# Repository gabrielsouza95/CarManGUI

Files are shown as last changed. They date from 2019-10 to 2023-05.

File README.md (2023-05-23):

# CarManGUI

### The Project
 
The project is being developed in partnership with FEB Racing([facebook](https://www.facebook.com/equipefebracing))([instagram](https://www.instagram.com/febracing/?hl=pt)), the formula SAE team from Unesp, for the construction of a device for the team's car.

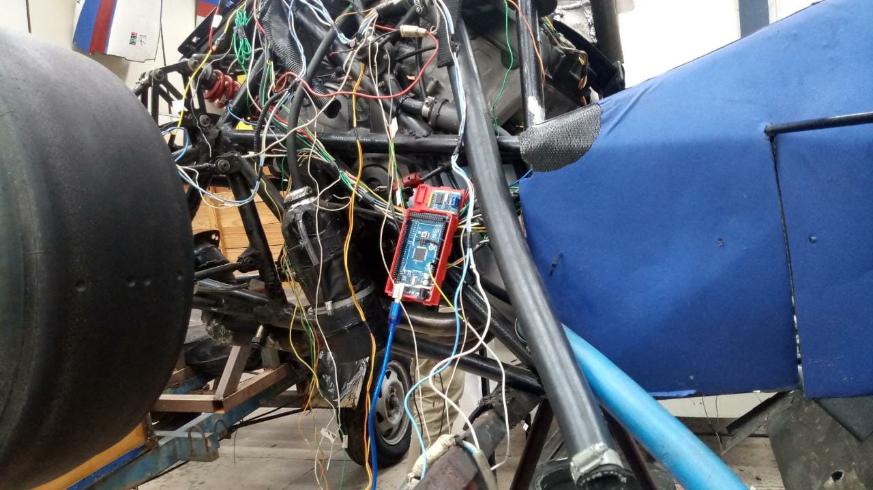
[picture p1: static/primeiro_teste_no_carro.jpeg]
First test on the car


In summary, it consists of:

1. Sensors placed on the car.
2. Recording of data collected from the sensors into a file for later analysis.
3. Displaying the data to the driver through a user interface and, in the future, to the team in the pit with the possibility of simple communication between the team and the driver:
   
    i. For example, showing the driver that a flag of color x has been given.
4. A plotter for data visualization and analysis.

### The Hardware
   
The current hardware of the project consists of:

1. 1 [Arduino Mega](https://www.arduino.cc/en/Guide/ArduinoMega2560)
2. Several sensors, including:

   i. 3 [MPU6050](https://www.letscontrolit.com/wiki/index.php/MPU6050) accelerometers and gyroscopes

   ii. 4 [MLX90614](https://forum.arduino.cc/index.php?topic=577921.0) infrared temperature sensors

   iii. 4 [KY003](https://www.instructables.com/Arduino-Magnetic-FIELD-Detector-Using-the-KY-003-o/) hall effect sensors

   iv. 4 potentiometers for suspension travel verification
   
    v. 1 brake line pressure sensor

3. 1 [0.96" OLED display](https://randomnerdtutorials.com/guide-for-oled-display-with-arduino/) that communicates via I2C
4. 3 buttons connected with a common pull-up
5. 1 [Raspberry Pi](https://circuitdigest.com/simple-raspberry-pi-projects-for-beginners)
6. 1 [3.5" touch displa](https://www.youtube.com/watch?v=Fj3wq98pd20), mounted on top of the Raspberry Pi, enabled via Raspbian
7. 1 4052 multiplexer
8. 1 [MCP2515](https://www.electronicshub.org/arduino-mcp2515-can-bus-tutorial/) adapter

In addition, the following are being implemented:
  - 4 [ATtiny85](https://thewanderingengineer.com/2014/02/17/attiny-i2c-slave/) microcontrollers.

### The Software

For the project implementation, C# is being used for the user interface, using a .NET Framework 4 project and [Mono].(https://www.mono-project.com/docs/getting-started/install/linux/#debian-ubuntu-and-derivatives)In the future, the Python will be used, which is compatible with Raspbian.

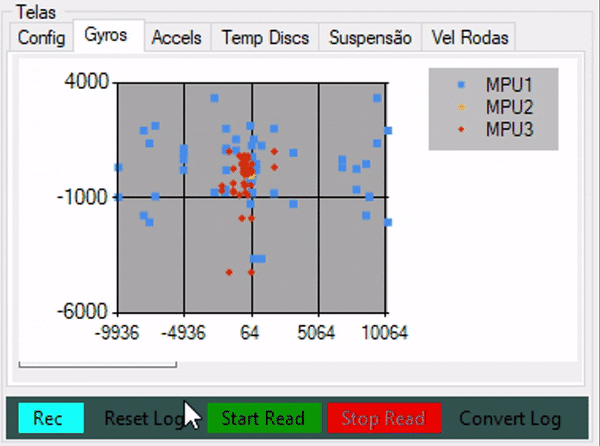
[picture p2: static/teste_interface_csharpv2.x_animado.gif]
teste_interface_csharpv2.x_animado


__The GIF shows a test of the C# window, with a 2D graph implemented, printing the values of 2 out of 3 accelerometer axes as data points while I sway the sensor.__

The project also utilizes Python, R, and C++ (Arduino, Processing, and an attempt to script for serial communication).

### Current Status

_-_ The project currently has a C# window developed to interface with the user through the Raspberry Pi's 3.5" display. It handles the initialization and termination of communication with the Arduino, controls when data recording starts, provides feedback when recording is in progress, and allows the recording to be stopped at any time*. It also displays sensor data on separate screens for better visualization.

_-_ The C# window did not function correctly on the Raspberry Pi after changing from manually using a thread to utilizing serial port events in C#. From my findings, the compatibility software Mono that I am using on the Raspberry Pi does not have the serial port event compatibility implemented.

_-_ Since the C# window did not work correctly on the Raspberry Pi, a 0.96" OLED display is being used to show desired information to the driver. It includes 2 buttons for menu selection, one for moving forward in the options and another for going back. The third button controls when the Arduino should start or stop recording. A SD card shield was supposed to be used, but it also did not work.

_-_ A Python window was developed to enable taking the functioning equipment to the competition since the SD module did not work directly connected to the Arduino. With this window, the Arduino can establish a connection and generate the log file. Due to the pandemic, it has not been possible to test the equipment on the team's car, but I will test it on my Corsa and post the results here. I will also test before and after installing the sway bar, as at that time, entry-level cars came so barebones that they didn't even come with safety features like the sway bar or the engine protection shield to reduce costs.

_-_ A test bench was created to facilitate the current bench tests, as seen in the following two images:

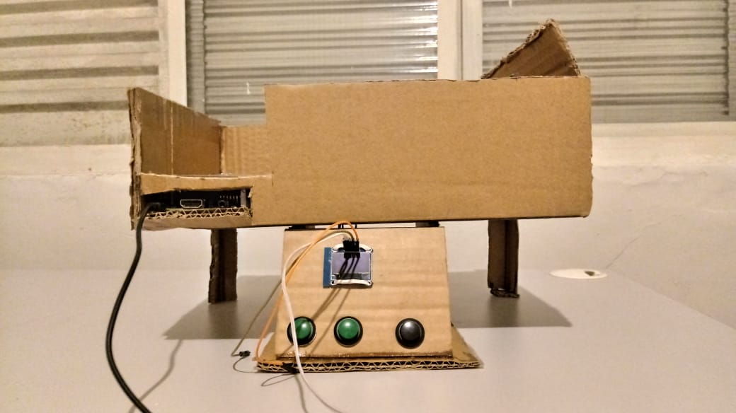
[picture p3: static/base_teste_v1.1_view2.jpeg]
Front view of the test bench


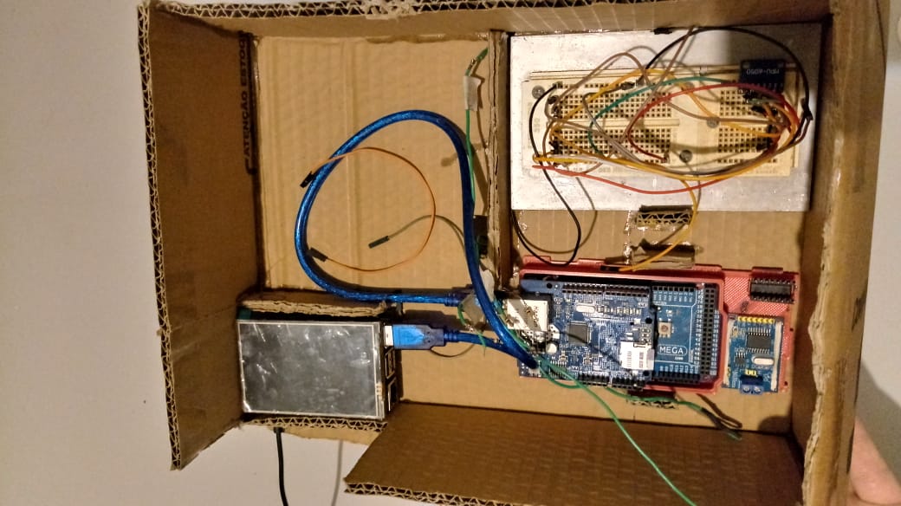
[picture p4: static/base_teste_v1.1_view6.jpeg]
Top view of the test bench


_-_ A flag alert feature was implemented to inform the driver of any conditions that require attention. This implementation allows for other necessary alerts to be conveyed to the driver. The image below shows how the accelerometer information was displayed:

Flag alert test

_-_ The interface for accelerometer data has been improved to be more comprehensible for the driver. The lateral and forward-backward acceleration axes were chosen for implementation in how the point should move. I took inspiration from the G-force display in Gran Turismo. The following image shows the first version:

First version of the accelerometer UI

_-_ In the next image, the second version of the interface can be seen:

Second version of the accelerometer UI

### Planned Implementations

_-_ I plan to use Johnny-Five with Node.js to communicate between the Raspberry Pi and Arduino. I am also studying the possibility of creating an interface with React and preparing it for accessing the car via the internet on a computer in the pit using a React web page or even a mobile app with React Native.

_-_ As mentioned in the software section, before implementing with JS([JonhyFive](http://johnny-five.io/),[Node](https://www.instructables.com/NodeJs-and-Arduino/),[React](https://awot.net/en/guide/tutorial.html),ReactNative), I will likely implement a version using Python, which guarantees compatibility with Raspbian.

_-_ The ATtiny85 microcontrollers will be used as speed sensors, placed between the Arduino and the hall effect sensor, to correctly count pulses per time interval. If we were to directly use the 4 hall effect sensors on the Arduino, [the response would be poor](https://forum.arduino.cc/index.php?topic=519300.0) due to how wheel speed is calculated by sampling pulses per time. This is because it utilizes interrupt routines of the processor for such tasks. The idea is to have the ATtiny85 connected as a [slave on the I2C bus](https://thewanderingengineer.com/2014/02/17/attiny-i2c-slave/), and when the Arduino requests it, the ATtiny85 will send the current wheel speed, performing the interrupt calculations directly on the ATtiny85, which supports this. 

_-_ I am considering migrating the project directly to an [ESP8266](https://github.com/esp8266/Arduino) to not only utilize WiFi functionality in conjunction with the Raspberry Pi but also to improve the speed of the hardware responsible for capturing sensor data. This would allow for better sampling of sensor data and the possibility of adding more data capture, such as a CAN adapter and additional sensors.

_-_ I want to include reading the CAN bus in the equipment. I am currently trying to make it work with the [MCP2515](https://www.electronicshub.org/arduino-mcp2515-can-bus-tutorial/) adapter, but so far, I have been unable to initialize the adapter to proceed with reading the data from the engine control unit (ECU) to associate it with the sensor data log added by the project.

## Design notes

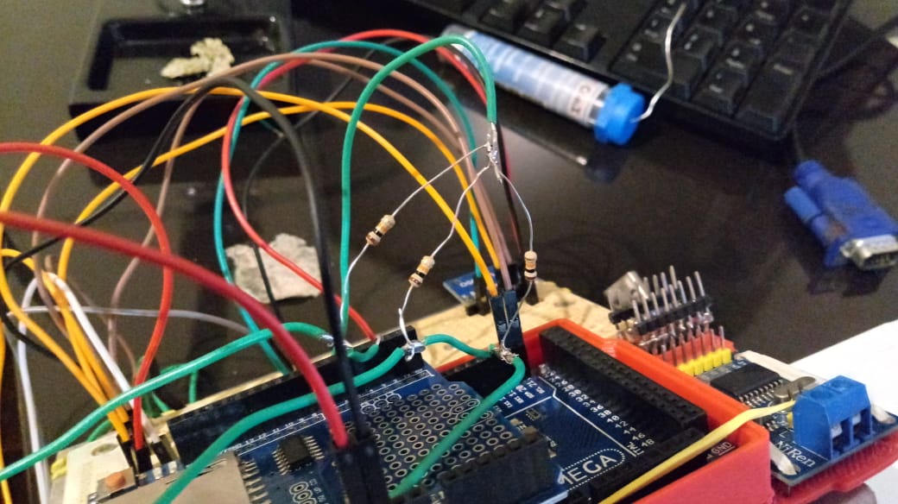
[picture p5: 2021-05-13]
static/pull_up_botões.jpeg

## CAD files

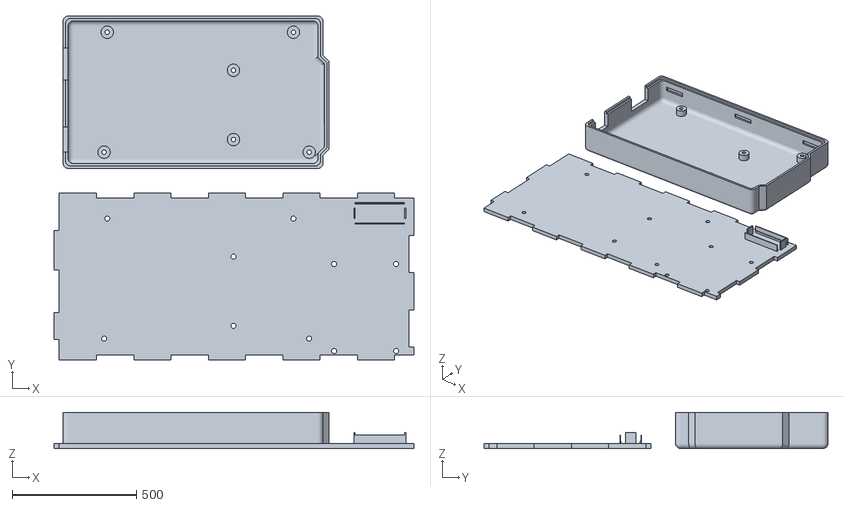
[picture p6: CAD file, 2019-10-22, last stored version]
3DArduinoCase/files/arduino_mega_bottom_extra v9.stl
1446.8 x 1384.3 x 145.3

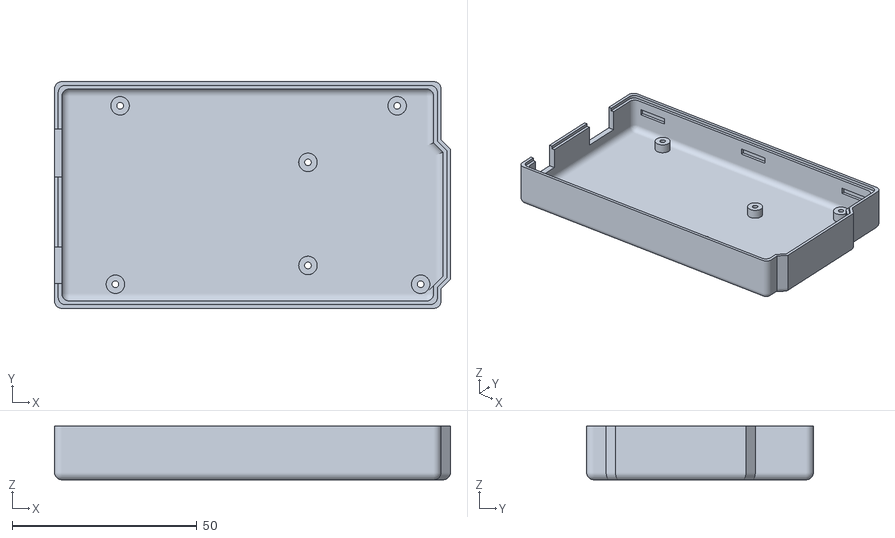
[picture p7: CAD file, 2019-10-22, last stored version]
3DArduinoCase/files/arduino_mega_bottom.stl
107.1 x 61.3 x 14.5

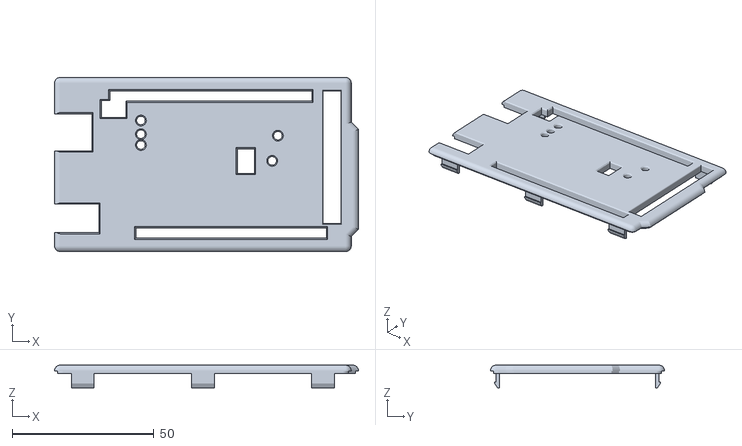
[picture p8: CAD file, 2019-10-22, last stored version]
3DArduinoCase/files/arduino_mega_top.stl
107.1 x 61.3 x 8.00

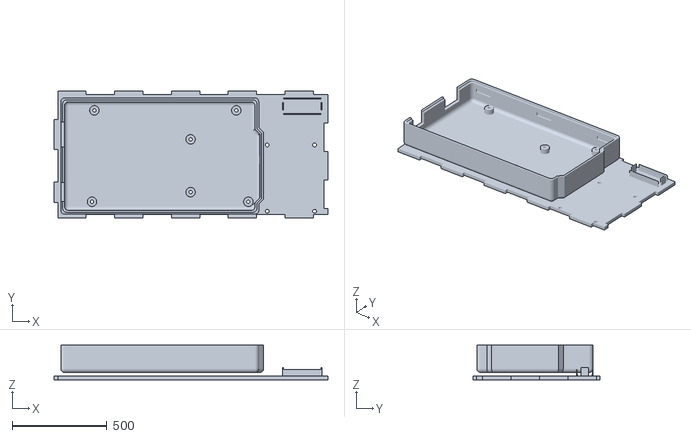
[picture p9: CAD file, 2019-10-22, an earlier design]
3DArduinoCase/files/arduino_mega_bottom_extra v8.stl
1446.8 x 671.8 x 184.3

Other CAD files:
3DArduinoCase/files/arduino_mega_bottom_extra ajutado.stl

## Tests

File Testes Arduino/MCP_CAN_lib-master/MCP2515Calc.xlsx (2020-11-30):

MCP2515 Configuration Register Calculator
Crystal Frequency | 16 | MHz | Baud Register Values |  |  |  | Misc Register Values
Baud Rate | 250 | kbs | Baud Rate Prescaler (BRP) |  |  | 1 | PS2 Bit Time Mode (BTLMODE) |  |  | 1
 |  |  | Propogation Segment |  |  | 1 | Sample Mode (SAM) |  |  | 1
Time Quantum | 0.25 | microseconds | Phase Segment 1 (PS1) |  |  | 6 | Start-of Frame Signal (SOF) |  |  | 1
Bit Time | 4 | microseconds | Phase Segment 2 (PS2) |  |  | 5 | Wake-Up Filter (WAKFIL) |  |  | 0
Time Quantum Max | 16 |  | Synchronization Jump Width (SJW) |  |  | 1
Prescaler Setting | 1 |  | Adjust BRP To Get A Nice Whole Time Quantum Max Value
SJW | 2 | x TQ | PropSeg + PS1 >= PS2 |  |  | Bit Sample Point Occurs Between PS1 and PS2
SyncSeg | 1 | x TQ | PropSeg + PS1 >= TDELAY |  |  | Typically, the TDELAY is 1-2 TQ
PropSeg | 2 | x TQ | PS2 > SJW
PS1 | 7 | x TQ | MCP2515 Baud Registers
PS2 | 6 | x TQ | msb |  |  |  |  |  |  | lsb
 | 16 | Total TQ | 7 | 6 | 5 | 4 | 3 | 2 | 1 | 0
Register CNF1 | 41 | 01000001 | 0 | 1 | 0 | 0 | 0 | 0 | 0 | 1
 |  |  | SJW |  | BRP
Register CNF2 | F1 | 11110001 | 1 | 1 | 1 | 1 | 0 | 0 | 0 | 1
 |  |  | BTLMODE | SAM | PS1 |  |  | Prop
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

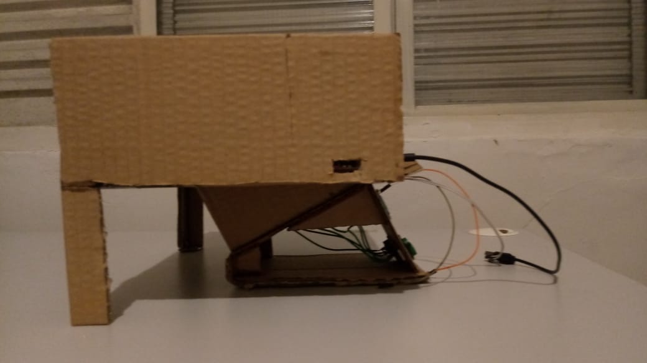
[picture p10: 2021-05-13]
static/base_teste_v1.1_view3.jpeg

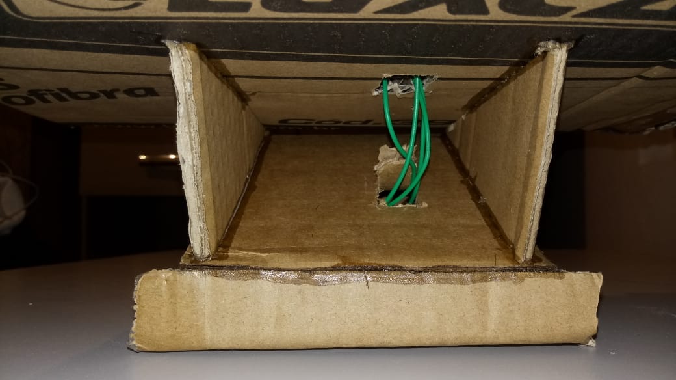
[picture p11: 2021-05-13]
static/base_teste_v1.1_view5.jpeg

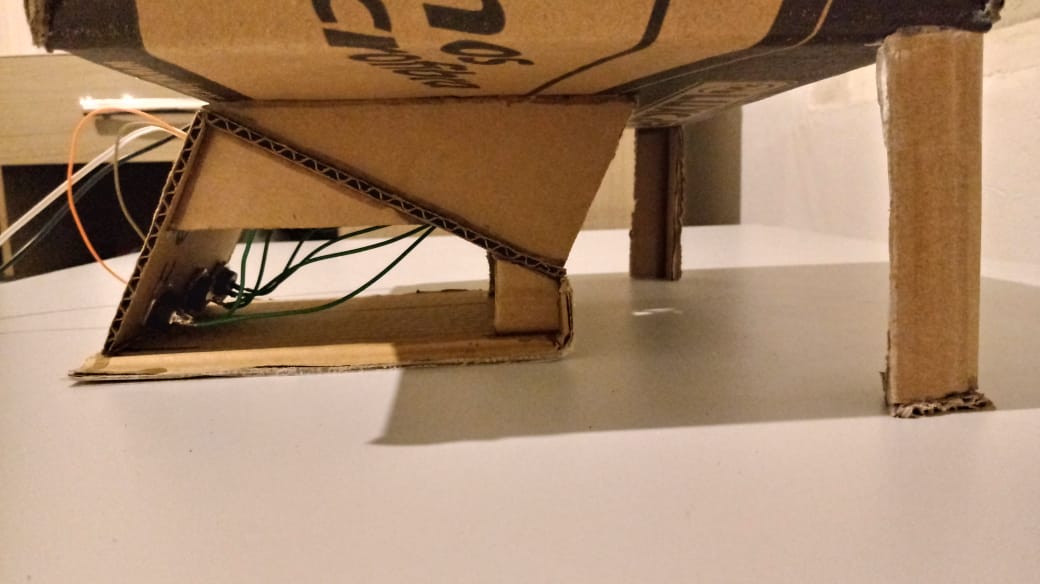
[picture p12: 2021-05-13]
static/base_teste_v1.1_view4.jpeg

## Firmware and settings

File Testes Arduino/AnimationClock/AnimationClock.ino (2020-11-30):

#include <SPI.h>
#include <Wire.h>
#include <Adafruit_GFX.h>
#include <Adafruit_SSD1306.h> 
//#include <Fonts/FreeSans9pt7b.h>
//#include <Fonts/FreeSans12pt7b.h>
//#include <Fonts/FreeSans18pt7b.h>

#define ARRAY_WIDTH 288
#define ARRAY_ELEMS 28
#define OLED_RESET -1
Adafruit_SSD1306 display(OLED_RESET);
const unsigned char PROGMEM frames  [28] [288] = { {0x00, 0x00, 0x00, 0x00, 0x00, 0x00, 0x00, 0x78, 0x00, 0x00, 0x3C, 0x00, 0x01, 0xFF, 0x00, 0x00, 0xFF, 0x80, 0x07, 0xEF, 0x00, 0x00, 0xFB, 0xE0, 0x0F, 0x0E, 0x00, 0x00, 0x70, 0xF0, 0x1E, 0x3C, 0x1F, 0xF0, 0x3C, 0x30, 0x18, 0x38, 0x7F, 0xFF, 0x1C, 0x38, 0x18, 0xF3, 0xF8, 0x2F, 0xCF, 0x1C, 0x38, 0xE7, 0xC0, 0x03, 0xE7, 0x1C, 0x33, 0xDE, 0x00, 0x00, 0x7B, 0xCC, 0x33, 0xBC, 0x00, 0x00, 0x3D, 0xCC, 0x3F, 0x78, 0x00, 0x00, 0x1E, 0xFC, 0x3F, 0x70, 0x00, 0x00, 0x0E, 0x7C, 0x3C, 0xE0, 0x00, 0x00, 0x07, 0x3C, 0x39, 0xC0, 0x00, 0x00, 0x03, 0x9C, 0x11, 0x82, 0x00, 0x00, 0x01, 0x88, 0x03, 0x87, 0x00, 0x00, 0x01, 0xC0, 0x03, 0x03, 0x80, 0x00, 0x00, 0xC0, 0x07, 0x01, 0xC0, 0x00, 0x00, 0xE0, 0x06, 0x00, 0xE0, 0x00, 0x00, 0x60, 0x0E, 0x00, 0x70, 0x00, 0x00, 0x60, 0x0E, 0x00, 0x38, 0x00, 0x00, 0x70, 0x0C, 0x00, 0x1C, 0x00, 0x00, 0x30, 0x0C, 0x00, 0x0E, 0x00, 0x00, 0x30, 0x0C, 0x00, 0x7F, 0x80, 0x00, 0x30, 0x0C, 0x01, 0xFF, 0x80, 0x00, 0x30, 0x0C, 0x00, 0x55, 0x00, 0x00, 0x30, 0x0C, 0x00, 0x00, 0x00, 0x00, 0x30, 0x0C, 0x00, 0x00, 0x00, 0x00, 0x30, 0x0C, 0x00, 0x00, 0x00, 0x00, 0x30, 0x0E, 0x00, 0x00, 0x00, 0x00, 0x70, 0x06, 0x00, 0x00, 0x00, 0x00, 0x60, 0x06, 0x00, 0x00, 0x00, 0x00, 0x60, 0x07, 0x00, 0x00, 0x00, 0x00, 0xE0, 0x03, 0x00, 0x00, 0x00, 0x00, 0xC0, 0x03, 0x80, 0x00, 0x00, 0x01, 0xC0, 0x01, 0xC0, 0x00, 0x00, 0x03, 0x80, 0x01, 0xC0, 0x00, 0x00, 0x03, 0x80, 0x00, 0xE0, 0x00, 0x00, 0x07, 0x00, 0x00, 0x70, 0x00, 0x00, 0x0E, 0x00, 0x00, 0x78, 0x00, 0x00, 0x1E, 0x00, 0x00, 0xFE, 0x00, 0x00, 0x7F, 0x00, 0x01, 0xCF, 0x80, 0x01, 0xF3, 0x80, 0x03, 0x83, 0xF0, 0x1F, 0xC1, 0xC0, 0x07, 0x00, 0xFF, 0xFF, 0x00, 0xE0, 0x06, 0x00, 0x1F, 0xF8, 0x00, 0x60, 0x00, 0x00, 0x00, 0x00, 0x00, 0x00, 0x00, 0x00, 0x00, 0x00, 0x00, 0x00}//;
/*const unsigned char PROGMEM frame1  [] =*/	 , {0x00, 0x00, 0x00, 0x00, 0x00, 0x00, 0x00, 0x78, 0x00, 0x00, 0x3C, 0x00, 0x01, 0xFF, 0x00, 0x00, 0xFF, 0x80, 0x07, 0xEF, 0x00, 0x00, 0xFB, 0xE0, 0x0F, 0x0E, 0x00, 0x00, 0x70, 0xF0, 0x1E, 0x3C, 0x1F, 0xF0, 0x3C, 0x30, 0x18, 0x38, 0x7F, 0xFF, 0x1C, 0x38, 0x18, 0xF3, 0xF8, 0x2F, 0xCF, 0x1C, 0x38, 0xE7, 0xC0, 0x03, 0xE7, 0x1C, 0x33, 0xDE, 0x00, 0x00, 0x7B, 0xCC, 0x33, 0xBC, 0x00, 0x00, 0x3D, 0xCC, 0x3F, 0x78, 0x00, 0x00, 0x1E, 0xFC, 0x3F, 0x70, 0x00, 0x00, 0x0E, 0x7C, 0x3C, 0xE0, 0x00, 0x00, 0x07, 0x3C, 0x39, 0xC0, 0x00, 0x00, 0x03, 0x9C, 0x11, 0x83, 0x80, 0x00, 0x01, 0x88, 0x03, 0x81, 0xC0, 0x00, 0x01, 0xC0, 0x03, 0x00, 0xE0, 0x00, 0x00, 0xC0, 0x07, 0x00, 0xE0, 0x00, 0x00, 0xE0, 0x06, 0x00, 0x70, 0x00, 0x00, 0x60, 0x0E, 0x00, 0x38, 0x00, 0x00, 0x60, 0x0E, 0x00, 0x1C, 0x00, 0x00, 0x70, 0x0C, 0x00, 0x0E, 0x00, 0x00, 0x30, 0x0C, 0x00, 0x07, 0x00, 0x00, 0x30, 0x0C, 0x00, 0x7F, 0x80, 0x00, 0x30, 0x0C, 0x01, 0xFF, 0x80, 0x00, 0x30, 0x0C, 0x00, 0x55, 0x00, 0x00, 0x30, 0x0C, 0x00, 0x00, 0x00, 0x00, 0x30, 0x0C, 0x00, 0x00, 0x00, 0x00, 0x30, 0x0C, 0x00, 0x00, 0x00, 0x00, 0x30, 0x0E, 0x00, 0x00, 0x00, 0x00, 0x70, 0x06, 0x00, 0x00, 0x00, 0x00, 0x60, 0x06, 0x00, 0x00, 0x00, 0x00, 0x60, 0x07, 0x00, 0x00, 0x00, 0x00, 0xE0, 0x03, 0x00, 0x00, 0x00, 0x00, 0xC0, 0x03, 0x80, 0x00, 0x00, 0x01, 0xC0, 0x01, 0xC0, 0x00, 0x00, 0x03, 0x80, 0x01, 0xC0, 0x00, 0x00, 0x03, 0x80, 0x00, 0xE0, 0x00, 0x00, 0x07, 0x00, 0x00, 0x70, 0x00, 0x00, 0x0E, 0x00, 0x00, 0x78, 0x00, 0x00, 0x1E, 0x00, 0x00, 0xFE, 0x00, 0x00, 0x7F, 0x00, 0x01, 0xCF, 0x80, 0x01, 0xF3, 0x80, 0x03, 0x83, 0xF0, 0x1F, 0xC1, 0xC0, 0x07, 0x00, 0xFF, 0xFF, 0x00, 0xE0, 0x06, 0x00, 0x1F, 0xF8, 0x00, 0x60, 0x00, 0x00, 0x00, 0x00, 0x00, 0x00, 0x00, 0x00, 0x00, 0x00, 0x00, 0x00}//;
/*const unsigned char PROGMEM frame2  [] =*/	 , {0x00, 0x00, 0x00, 0x00, 0x00, 0x00, 0x00, 0x78, 0x00, 0x00, 0x3C, 0x00, 0x01, 0xFF, 0x00, 0x00, 0xFF, 0x80, 0x07, 0xEF, 0x00, 0x00, 0xFB, 0xE0, 0x0F, 0x0E, 0x00, 0x00, 0x70, 0xF0, 0x1E, 0x3C, 0x1F, 0xF0, 0x3C, 0x38, 0x18, 0x38, 0x7F, 0xFF, 0x1C, 0x38, 0x18, 0xF3, 0xF8, 0x2F, 0xCF, 0x1C, 0x38, 0xE7, 0xC0, 0x03, 0xE7, 0x1C, 0x33, 0xDE, 0x00, 0x00, 0x7B, 0xCC, 0x33, 0xBC, 0x00, 0x00, 0x3D, 0xCC, 0x3F, 0x78, 0x00, 0x00, 0x1E, 0xFC, 0x3F, 0x70, 0x00, 0x00, 0x0E, 0x7C, 0x3C, 0xE0, 0x00, 0x00, 0x07, 0x3C, 0x39, 0xC0, 0xC0, 0x00, 0x03, 0x9C, 0x11, 0x80, 0xE0, 0x00, 0x01, 0x88, 0x03, 0x80, 0xE0, 0x00, 0x01, 0xC0, 0x03, 0x00, 0x70, 0x00, 0x00, 0xE0, 0x07, 0x00, 0x30, 0x00, 0x00, 0xE0, 0x06, 0x00, 0x38, 0x00, 0x00, 0x60, 0x0E, 0x00, 0x1C, 0x00, 0x00, 0x60, 0x0E, 0x00, 0x0C, 0x00, 0x00, 0x70, 0x0C, 0x00, 0x0E, 0x00, 0x00, 0x30, 0x0C, 0x00, 0x07, 0x00, 0x00, 0x30, 0x0C, 0x00, 0x7F, 0x80, 0x00, 0x30, 0x0C, 0x01, 0xFF, 0x80, 0x00, 0x30, 0x0C, 0x00, 0x55, 0x00, 0x00, 0x30, 0x0C, 0x00, 0x00, 0x00, 0x00, 0x30, 0x0C, 0x00, 0x00, 0x00, 0x00, 0x30, 0x0C, 0x00, 0x00, 0x00, 0x00, 0x30, 0x0E, 0x00, 0x00, 0x00, 0x00, 0x70, 0x06, 0x00, 0x00, 0x00, 0x00, 0x60, 0x06, 0x00, 0x00, 0x00, 0x00, 0x60, 0x07, 0x00, 0x00, 0x00, 0x00, 0xE0, 0x03, 0x00, 0x00, 0x00, 0x00, 0xC0, 0x03, 0x80, 0x00, 0x00, 0x01, 0xC0, 0x01, 0xC0, 0x00, 0x00, 0x03, 0x80, 0x01, 0xC0, 0x00, 0x00, 0x03, 0x80, 0x00, 0xE0, 0x00, 0x00, 0x07, 0x00, 0x00, 0x70, 0x00, 0x00, 0x0E, 0x00, 0x00, 0x78, 0x00, 0x00, 0x1E, 0x00, 0x00, 0xFE, 0x00, 0x00, 0x7F, 0x00, 0x01, 0xCF, 0x80, 0x01, 0xF3, 0x80, 0x03, 0x83, 0xF0, 0x1F, 0xC1, 0xC0, 0x07, 0x00, 0xFF, 0xFF, 0x00, 0xE0, 0x06, 0x00, 0x1F, 0xF8, 0x00, 0x60, 0x00, 0x00, 0x00, 0x00, 0x00, 0x00, 0x00, 0x00, 0x00, 0x00, 0x00, 0x00}//;
/*const unsigned char PROGMEM frame3  [] =*/	 , {0x00, 0x00, 0x00, 0x00, 0x00, 0x00, 0x00, 0x78, 0x00, 0x00, 0x3C, 0x00, 0x01, 0xFF, 0x00, 0x00, 0xFF, 0x80, 0x07, 0xEF, 0x00, 0x00, 0xFB, 0xE0, 0x0F, 0x0E, 0x00, 0x00, 0x70, 0xF0, 0x1E, 0x3C, 0x1F, 0xF0, 0x3C, 0x30, 0x18, 0x38, 0x7F, 0xFF, 0x1C, 0x38, 0x18, 0xF3, 0xF8, 0x2F, 0xCF, 0x1C, 0x38, 0xE7, 0xC0, 0x03, 0xE7, 0x1C, 0x33, 0xDE, 0x00, 0x00, 0x7B, 0xCC, 0x33, 0xBC, 0x00, 0x00, 0x3D, 0xCC, 0x3F, 0x78, 0x00, 0x00, 0x1E, 0xFC, 0x3F, 0x70, 0x00, 0x00, 0x0E, 0x7C, 0x3C, 0xE0, 0x60, 0x00, 0x07, 0x3C, 0x39, 0xC0, 0x60, 0x00, 0x03, 0x9C, 0x11, 0x80, 0x70, 0x00, 0x01, 0x88, 0x03, 0x80, 0x30, 0x00, 0x01, 0xC0, 0x03, 0x00, 0x38, 0x00, 0x00, 0xC0, 0x07, 0x00, 0x18, 0x00, 0x00, 0xE0, 0x06, 0x00, 0x1C, 0x00, 0x00, 0x60, 0x0E, 0x00, 0x0C, 0x00, 0x00, 0x60, 0x0E, 0x00, 0x0E, 0x00, 0x00, 0x70, 0x0C, 0x00, 0x06, 0x00, 0x00, 0x30, 0x0C, 0x00, 0x03, 0x00, 0x00, 0x30, 0x0C, 0x00, 0x7F, 0x80, 0x00, 0x30, 0x0C, 0x01, 0xFF, 0x80, 0x00, 0x30, 0x0C, 0x00, 0x55, 0x00, 0x00, 0x30, 0x0C, 0x00, 0x00, 0x00, 0x00, 0x30, 0x0C, 0x00, 0x00, 0x00, 0x00, 0x30, 0x0C, 0x00, 0x00, 0x00, 0x00, 0x30, 0x0E, 0x00, 0x00, 0x00, 0x00, 0x70, 0x06, 0x00, 0x00, 0x00, 0x00, 0x60, 0x06, 0x00, 0x00, 0x00, 0x00, 0x60, 0x07, 0x00, 0x00, 0x00, 0x00, 0xE0, 0x03, 0x00, 0x00, 0x00, 0x00, 0xC0, 0x03, 0x80, 0x00, 0x00, 0x01, 0xC0, 0x01, 0xC0, 0x00, 0x00, 0x03, 0x80, 0x01, 0xC0, 0x00, 0x00, 0x03, 0x80, 0x00, 0xE0, 0x00, 0x00, 0x07, 0x00, 0x00, 0x70, 0x00, 0x00, 0x0E, 0x00, 0x00, 0x78, 0x00, 0x00, 0x1E, 0x00, 0x00, 0xFE, 0x00, 0x00, 0x7F, 0x00, 0x01, 0xCF, 0x80, 0x01, 0xF3, 0x80, 0x03, 0x83, 0xF0, 0x1F, 0xC1, 0xC0, 0x07, 0x00, 0xFF, 0xFF, 0x00, 0xE0, 0x06, 0x00, 0x1F, 0xF8, 0x00, 0x60, 0x00, 0x00, 0x00, 0x00, 0x00, 0x00, 0x00, 0x00, 0x00, 0x00, 0x00, 0x00}//;
/*const unsigned char PROGMEM frame4  [] =*/	 , {0x00, 0x00, 0x00, 0x00, 0x00, 0x00, 0x00, 0x78, 0x00, 0x00, 0x3C, 0x00, 0x01, 0xFF, 0x00, 0x00, 0xFF, 0x80, 0x07, 0xEF, 0x00, 0x00, 0xFB, 0xE0, 0x0F, 0x0E, 0x00, 0x00, 0x70, 0xF0, 0x1E, 0x3C, 0x1F, 0xF0, 0x3C, 0x30, 0x18, 0x38, 0x7F, 0xFF, 0x1C, 0x38, 0x18, 0xF3, 0xF8, 0x2F, 0xCF, 0x1C, 0x38, 0xE7, 0xC0, 0x03, 0xE7, 0x1C, 0x33, 0xDE, 0x00, 0x00, 0x7B, 0xCC, 0x33, 0xBC, 0x00, 0x00, 0x3D, 0xCC, 0x3F, 0x78, 0x00, 0x00, 0x1E, 0xFC, 0x3F, 0x70, 0x10, 0x00, 0x0E, 0x7C, 0x3C, 0xE0, 0x30, 0x00, 0x07, 0x3C, 0x39, 0xC0, 0x38, 0x00, 0x03, 0x9C, 0x11, 0x80, 0x18, 0x00, 0x01, 0x88, 0x03, 0x80, 0x18, 0x00, 0x01, 0xC0, 0x03, 0x00, 0x1C, 0x00, 0x00, 0xC0, 0x07, 0x00, 0x0C, 0x00, 0x00, 0xE0, 0x06, 0x00, 0x0E, 0x00, 0x00, 0x60, 0x0E, 0x00, 0x06, 0x00, 0x00, 0x60, 0x0E, 0x00, 0x06, 0x00, 0x00, 0x70, 0x0C, 0x00, 0x07, 0x00, 0x00, 0x30, 0x0C, 0x00, 0x03, 0x00, 0x00, 0x30, 0x0C, 0x00, 0x7F, 0x80, 0x00, 0x30, 0x0C, 0x01, 0xFF, 0x80, 0x00, 0x30, 0x0C, 0x00, 0x55, 0x00, 0x00, 0x30, 0x0C, 0x00, 0x00, 0x00, 0x00, 0x30, 0x0C, 0x00, 0x00, 0x00, 0x00, 0x30, 0x0C, 0x00, 0x00, 0x00, 0x00, 0x30, 0x0E, 0x00, 0x00, 0x00, 0x00, 0x70, 0x06, 0x00, 0x00, 0x00, 0x00, 0x60, 0x06, 0x00, 0x00, 0x00, 0x00, 0x60, 0x07, 0x00, 0x00, 0x00, 0x00, 0xE0, 0x03, 0x00, 0x00, 0x00, 0x00, 0xC0, 0x03, 0x80, 0x00, 0x00, 0x01, 0xC0, 0x01, 0xC0, 0x00, 0x00, 0x03, 0x80, 0x01, 0xC0, 0x00, 0x00, 0x03, 0x80, 0x00, 0xE0, 0x00, 0x00, 0x07, 0x00, 0x00, 0x70, 0x00, 0x00, 0x0E, 0x00, 0x00, 0x78, 0x00, 0x00, 0x1E, 0x00, 0x00, 0xFE, 0x00, 0x00, 0x7F, 0x00, 0x01, 0xCF, 0x80, 0x01, 0xF3, 0x80, 0x03, 0x83, 0xF0, 0x1F, 0xC1, 0xC0, 0x07, 0x00, 0xFF, 0xFF, 0x00, 0xE0, 0x06, 0x00, 0x1F, 0xF8, 0x00, 0x60, 0x00, 0x00, 0x00, 0x00, 0x00, 0x00, 0x00, 0x00, 0x00, 0x00, 0x00, 0x00}//;
/*const unsigned char PROGMEM frame5  [] =*/	 , {0x00, 0x00, 0x00, 0x00, 0x00, 0x00, 0x00, 0x78, 0x00, 0x00, 0x3C, 0x00, 0x01, 0xFF, 0x00, 0x00, 0xFF, 0x80, 0x07, 0xEF, 0x00, 0x00, 0xFB, 0xE0, 0x0F, 0x0E, 0x00, 0x00, 0x70, 0xF0, 0x1E, 0x3C, 0x1F, 0xF0, 0x3C, 0x30, 0x18, 0x38, 0x7F, 0xFF, 0x1C, 0x38, 0x18, 0xF3, 0xF8, 0x2F, 0xCF, 0x1C, 0x38, 0xE7, 0xC0, 0x03, 0xE7, 0x1C, 0x33, 0xDE, 0x00, 0x00, 0x7B, 0xCC, 0x33, 0xBC, 0x00, 0x00, 0x3D, 0xCC, 0x3F, 0x78, 0x00, 0x00, 0x1E, 0xFC, 0x3F, 0x70, 0x08, 0x00, 0x0E, 0x7C, 0x3C, 0xE0, 0x1C, 0x00, 0x07, 0x3C, 0x39, 0xC0, 0x1C, 0x00, 0x03, 0x9C, 0x11, 0x80, 0x0C, 0x00, 0x01, 0x88, 0x03, 0x80, 0x0C, 0x00, 0x01, 0xC0, 0x03, 0x00, 0x0E, 0x00, 0x00, 0xC0, 0x07, 0x00, 0x06, 0x00, 0x00, 0xE0, 0x06, 0x00, 0x06, 0x00, 0x00, 0x60, 0x0E, 0x00, 0x07, 0x00, 0x00, 0x60, 0x0E, 0x00, 0x03, 0x00, 0x00, 0x70, 0x0C, 0x00, 0x03, 0x00, 0x00, 0x30, 0x0C, 0x00, 0x03, 0x80, 0x00, 0x30, 0x0C, 0x00, 0x7F, 0x80, 0x00, 0x30, 0x0C, 0x01, 0xFF, 0x80, 0x00, 0x30, 0x0C, 0x00, 0x55, 0x00, 0x00, 0x30, 0x0C, 0x00, 0x00, 0x00, 0x00, 0x30, 0x0C, 0x00, 0x00, 0x00, 0x00, 0x30, 0x0C, 0x00, 0x00, 0x00, 0x00, 0x30, 0x0E, 0x00, 0x00, 0x00, 0x00, 0x70, 0x06, 0x00, 0x00, 0x00, 0x00, 0x60, 0x06, 0x00, 0x00, 0x00, 0x00, 0x60, 0x07, 0x00, 0x00, 0x00, 0x00, 0xE0, 0x03, 0x00, 0x00, 0x00, 0x00, 0xC0, 0x03, 0x80, 0x00, 0x00, 0x01, 0xC0, 0x01, 0xC0, 0x00, 0x00, 0x03, 0x80, 0x01, 0xC0, 0x00, 0x00, 0x03, 0x80, 0x00, 0xE0, 0x00, 0x00, 0x07, 0x00, 0x00, 0x70, 0x00, 0x00, 0x0E, 0x00, 0x00, 0x78, 0x00, 0x00, 0x1E, 0x00, 0x00, 0xFE, 0x00, 0x00, 0x7F, 0x00, 0x01, 0xCF, 0x80, 0x01, 0xF3, 0x80, 0x03, 0x83, 0xF0, 0x1F, 0xC1, 0xC0, 0x07, 0x00, 0xFF, 0xFF, 0x00, 0xE0, 0x06, 0x00, 0x1F, 0xF8, 0x00, 0x60, 0x00, 0x00, 0x00, 0x00, 0x00, 0x00, 0x00, 0x00, 0x00, 0x00, 0x00, 0x00}//;
/*const unsigned char PROGMEM frame6  [] =*/	 , {0x00, 0x00, 0x00, 0x00, 0x00, 0x00, 0x00, 0x00, 0x00, 0x00, 0x68, 0x00, 0x00, 0x00, 0x00, 0x01, 0xFF, 0x00, 0x00, 0x50, 0x00, 0x03, 0xFF, 0x80, 0x03, 0xFC, 0x00, 0x01, 0xC1, 0xC0, 0x07, 0xFC, 0x00, 0x00, 0xF0, 0xE0, 0x1E, 0x38, 0x07, 0xF0, 0x78, 0x70, 0x38, 0x70, 0x7F, 0xFE, 0x3C, 0x30, 0x38, 0xE1, 0xFA, 0xBF, 0x9E, 0x30, 0x71, 0xC7, 0xC0, 0x03, 0xE7, 0xB8, 0x61, 0xCF, 0x00, 0x00, 0xF3, 0xB8, 0x63, 0xBC, 0x00, 0x00, 0x3D, 0xF8, 0x67, 0xB8, 0x00, 0x00, 0x1C, 0xF8, 0x6F, 0x70, 0x04, 0x00, 0x0E, 0x78, 0x6E, 0xE0, 0x0E, 0x00, 0x07, 0x30, 0x7D, 0xC0, 0x0E, 0x00, 0x03, 0x80, 0x79, 0x80, 0x06, 0x00, 0x01, 0x80, 0x73, 0x80, 0x06, 0x00, 0x01, 0xC0, 0x23, 0x00, 0x06, 0x00, 0x00, 0xC0, 0x07, 0x00, 0x07, 0x00, 0x00, 0xE0, 0x06, 0x00, 0x07, 0x00, 0x00, 0x60, 0x06, 0x00, 0x03, 0x00, 0x00, 0x60, 0x0E, 0x00, 0x03, 0x00, 0x00, 0x70, 0x0C, 0x00, 0x03, 0x00, 0x00, 0x30, 0x0C, 0x00, 0x03, 0x80, 0x00, 0x30, 0x0C, 0x00, 0xDB, 0x80, 0x00, 0x30, 0x0C, 0x01, 0xFF, 0x80, 0x00, 0x30, 0x0C, 0x00, 0xB7, 0x00, 0x00, 0x30, 0x0C, 0x00, 0x00, 0x00, 0x00, 0x30, 0x0C, 0x00, 0x00, 0x00, 0x00, 0x30, 0x0C, 0x00, 0x00, 0x00, 0x00, 0x30, 0x0E, 0x00, 0x00, 0x00, 0x00, 0x70, 0x06, 0x00, 0x00, 0x00, 0x00, 0x60, 0x06, 0x00, 0x00, 0x00, 0x00, 0x60, 0x07, 0x00, 0x00, 0x00, 0x00, 0xE0, 0x03, 0x00, 0x00, 0x00, 0x00, 0xC0, 0x03, 0x80, 0x00, 0x00, 0x01, 0xC0, 0x01, 0x80, 0x00, 0x00, 0x01, 0x80, 0x01, 0xC0, 0x00, 0x00, 0x03, 0x80, 0x00, 0xE0, 0x00, 0x00, 0x07, 0x00, 0x00, 0x70, 0x00, 0x00, 0x0E, 0x00, 0x00, 0x78, 0x00, 0x00, 0x1E, 0x00, 0x00, 0xFE, 0x00, 0x00, 0x7F, 0x00, 0x01, 0xCF, 0x80, 0x01, 0xF3, 0x80, 0x03, 0x83, 0xF0, 0x0F, 0xC1, 0xC0, 0x07, 0x00, 0xFF, 0xFF, 0x00, 0xE0, 0x06, 0x00, 0x1F, 0xFC, 0x00, 0x60, 0x00, 0x00, 0x00, 0x00, 0x00, 0x00}//;
/*const unsigned char PROGMEM frame7  [] =*/	 , {0x00, 0x00, 0x00, 0x00, 0x00, 0x00, 0x00, 0x00, 0x00, 0x00, 0x50, 0x00, 0x00, 0x00, 0x00, 0x03, 0xFE, 0x00, 0x00, 0x00, 0x00, 0x07, 0xFF, 0x00, 0x00, 0x00, 0x00, 0x07, 0xC3, 0x80, 0x03, 0xF8, 0x00, 0x01, 0xC1, 0xC0, 0x0F, 0xF8, 0x00, 0x00, 0xF0, 0xE0, 0x1E, 0x70, 0x1F, 0xF8, 0x78, 0x60, 0x38, 0xE0, 0xFF, 0xFF, 0x1C, 0x70, 0x70, 0xE3, 0xF0, 0x0F, 0xCF, 0x30, 0x61, 0xCF, 0x80, 0x01, 0xE7, 0xF0, 0x63, 0x9E, 0x00, 0x00, 0x79, 0xF0, 0xE3, 0x9C, 0x00, 0x00, 0x3D, 0xF0, 0xC7, 0x78, 0x02, 0x00, 0x1C, 0x70, 0xCF, 0x70, 0x06, 0x00, 0x0F, 0x30, 0xCC, 0xE0, 0x07, 0x00, 0x07, 0x00, 0xFD, 0xC0, 0x07, 0x00, 0x03, 0x80, 0xFB, 0x80, 0x03, 0x00, 0x01, 0xC0, 0xF3, 0x80, 0x03, 0x00, 0x00, 0xC0, 0x67, 0x00, 0x03, 0x00, 0x00, 0xE0, 0x26, 0x00, 0x03, 0x00, 0x00, 0xE0, 0x06, 0x00, 0x03, 0x00, 0x00, 0x60, 0x0E, 0x00, 0x03, 0x00, 0x00, 0x60, 0x0E, 0x00, 0x03, 0x80, 0x00, 0x70, 0x0C, 0x00, 0x03, 0x80, 0x00, 0x30, 0x0C, 0x00, 0x01, 0x80, 0x00, 0x30, 0x0C, 0x00, 0xFF, 0x80, 0x00, 0x30, 0x0C, 0x01, 0xFF, 0x80, 0x00, 0x30, 0x0C, 0x00, 0x00, 0x00, 0x00, 0x30, 0x0C, 0x00, 0x00, 0x00, 0x00, 0x30, 0x0C, 0x00, 0x00, 0x00, 0x00, 0x30, 0x0C, 0x00, 0x00, 0x00, 0x00, 0x30, 0x0E, 0x00, 0x00, 0x00, 0x00, 0x70, 0x06, 0x00, 0x00, 0x00, 0x00, 0x60, 0x07, 0x00, 0x00, 0x00, 0x00, 0xE0, 0x07, 0x00, 0x00, 0x00, 0x00, 0xE0, 0x03, 0x00, 0x00, 0x00, 0x00, 0xC0, 0x03, 0x80, 0x00, 0x00, 0x01, 0xC0, 0x01, 0x80, 0x00, 0x00, 0x03, 0x80, 0x00, 0xE0, 0x00, 0x00, 0x07, 0x00, 0x00, 0xE0, 0x00, 0x00, 0x07, 0x00, 0x00, 0x70, 0x00, 0x00, 0x0E, 0x00, 0x00, 0xFC, 0x00, 0x00, 0x3F, 0x00, 0x00, 0xFE, 0x00, 0x00, 0x7F, 0x00, 0x01, 0xC7, 0xC0, 0x01, 0xE3, 0x80, 0x03, 0x83, 0xF8, 0x2F, 0xC1, 0xC0, 0x07, 0x00, 0x7F, 0xFF, 0x00, 0xE0, 0x06, 0x00, 0x0F, 0xF0, 0x00, 0x60}//;
/*const unsigned char PROGMEM frame8  [] =*/	 , {0x00, 0x00, 0x00, 0x00, 0x00, 0x00, 0x00, 0x00, 0x00, 0x00, 0x00, 0x00, 0x00, 0x7E, 0x00, 0x00, 0x3F, 0x00, 0x03, 0xFF, 0x00, 0x00, 0xFF, 0xC0, 0x07, 0xCE, 0x00, 0x00, 0x79, 0xE0, 0x0F, 0x1E, 0x00, 0x00, 0x78, 0xF0, 0x1C, 0x38, 0x1F, 0xF8, 0x1C, 0x38, 0x18, 0x78, 0xFF, 0xFF, 0x1E, 0x18, 0x38, 0xE3, 0xF0, 0x0F, 0xC7, 0x1C, 0x38, 0xCF, 0x80, 0x01, 0xF7, 0x8C, 0x33, 0xDE, 0x00, 0x00, 0x79, 0xCC, 0x37, 0xB8, 0x00, 0x00, 0x1D, 0xEC, 0x37, 0x38, 0x01, 0x00, 0x1E, 0xFC, 0x3E, 0xF0, 0x03, 0x00, 0x0E, 0x7C, 0x3C, 0xE0, 0x03, 0x00, 0x07, 0x3C, 0x39, 0xC0, 0x03, 0x00, 0x03, 0x9C, 0x13, 0x80, 0x03, 0x80, 0x01, 0xC8, 0x03, 0x00, 0x03, 0x00, 0x00, 0xC0, 0x07, 0x00, 0x03, 0x80, 0x00, 0xE0, 0x07, 0x00, 0x01, 0x80, 0x00, 0x60, 0x06, 0x00, 0x03, 0x80, 0x00, 0x60, 0x06, 0x00, 0x01, 0x80, 0x00, 0x70, 0x0E, 0x00, 0x01, 0x80, 0x00, 0x70, 0x0C, 0x00, 0x01, 0x80, 0x00, 0x30, 0x0C, 0x00, 0x01, 0x80, 0x00, 0x30, 0x0C, 0x00, 0xFF, 0x80, 0x00, 0x30, 0x0C, 0x01, 0xFF, 0x80, 0x00, 0x30, 0x0C, 0x00, 0x00, 0x00, 0x00, 0x30, 0x0C, 0x00, 0x00, 0x00, 0x00, 0x30, 0x0C, 0x00, 0x00, 0x00, 0x00, 0x30, 0x0C, 0x00, 0x00, 0x00, 0x00, 0x30, 0x0E, 0x00, 0x00, 0x00, 0x00, 0x70, 0x06, 0x00, 0x00, 0x00, 0x00, 0x60, 0x07, 0x00, 0x00, 0x00, 0x00, 0x60, 0x03, 0x00, 0x00, 0x00, 0x00, 0xC0, 0x03, 0x80, 0x00, 0x00, 0x01, 0xC0, 0x03, 0x80, 0x00, 0x00, 0x01, 0xC0, 0x01, 0xC0, 0x00, 0x00, 0x01, 0x80, 0x00, 0xE0, 0x00, 0x00, 0x07, 0x00, 0x00, 0xE0, 0x00, 0x00, 0x07, 0x00, 0x00, 0x70, 0x00, 0x00, 0x0E, 0x00, 0x00, 0xFC, 0x00, 0x00, 0x3E, 0x00, 0x00, 0xFE, 0x00, 0x00, 0x7F, 0x80, 0x01, 0xC7, 0xC0, 0x03, 0xE3, 0x80, 0x03, 0x83, 0xFC, 0x1F, 0xC1, 0xC0, 0x07, 0x00, 0x7F, 0xFE, 0x00, 0xE0, 0x06, 0x00, 0x0F, 0xF0, 0x00, 0x60, 0x00, 0x00, 0x00, 0x00, 0x00, 0x00}//;
/*const unsigned char PROGMEM frame9  [] =*/	 , {0x00, 0x3F, 0xC0, 0x00, 0x00, 0x00, 0x01, 0xFF, 0xE0, 0x00, 0x00, 0x00, 0x01, 0xE3, 0xE0, 0x00, 0x00, 0x00, 0x03, 0x83, 0x80, 0x00, 0x1F, 0xC0, 0x07, 0x0F, 0x00, 0x00, 0x1F, 0xF0, 0x06, 0x1E, 0x1F, 0xF8, 0x0E, 0xF8, 0x0E, 0x78, 0xFF, 0xFF, 0x07, 0x1C, 0x0C, 0xF3, 0xF0, 0x0F, 0xC7, 0x0E, 0x0F, 0xEF, 0x80, 0x01, 0xF3, 0x86, 0x0F, 0x9E, 0x00, 0x00, 0x79, 0xC7, 0x0F, 0x38, 0x00, 0x00, 0x3C, 0xC7, 0x0E, 0x70, 0x01, 0x80, 0x0E, 0xE3, 0x04, 0x70, 0x01, 0x80, 0x0F, 0x73, 0x00, 0xE0, 0x01, 0x80, 0x07, 0x73, 0x01, 0xC0, 0x01, 0x80, 0x03, 0xBF, 0x03, 0x80, 0x01, 0x80, 0x01, 0xDF, 0x03, 0x00, 0x01, 0x80, 0x01, 0xCE, 0x07, 0x00, 0x01, 0x80, 0x00, 0xE6, 0x06, 0x00, 0x01, 0x80, 0x00, 0x64, 0x06, 0x00, 0x01, 0x80, 0x00, 0x60, 0x0E, 0x00, 0x01, 0x80, 0x00, 0x70, 0x0E, 0x00, 0x01, 0x80, 0x00, 0x70, 0x0C, 0x00, 0x01, 0x80, 0x00, 0x30, 0x0C, 0x00, 0x01, 0x80, 0x00, 0x30, 0x0C, 0x00, 0xFF, 0x80, 0x00, 0x30, 0x0C, 0x01, 0xFF, 0x80, 0x00, 0x30, 0x0C, 0x00, 0x00, 0x00, 0x00, 0x30, 0x0C, 0x00, 0x00, 0x00, 0x00, 0x30, 0x0C, 0x00, 0x00, 0x00, 0x00, 0x30, 0x0C, 0x00, 0x00, 0x00, 0x00, 0x30, 0x0E, 0x00, 0x00, 0x00, 0x00, 0x70, 0x06, 0x00, 0x00, 0x00, 0x00, 0x60, 0x07, 0x00, 0x00, 0x00, 0x00, 0xE0, 0x03, 0x00, 0x00, 0x00, 0x00, 0xC0, 0x03, 0x80, 0x00, 0x00, 0x01, 0xC0, 0x01, 0x80, 0x00, 0x00, 0x01, 0xC0, 0x01, 0xC0, 0x00, 0x00, 0x03, 0x80, 0x00, 0xC0, 0x00, 0x00, 0x07, 0x00, 0x00, 0xF0, 0x00, 0x00, 0x07, 0x00, 0x00, 0x70, 0x00, 0x00, 0x0E, 0x00, 0x00, 0xFC, 0x00, 0x00, 0x3F, 0x00, 0x00, 0xFE, 0x00, 0x00, 0x7F, 0x00, 0x03, 0xC7, 0xC0, 0x03, 0xE3, 0x80, 0x03, 0x83, 0xF8, 0x3F, 0xC1, 0xE0, 0x07, 0x00, 0x7F, 0xFE, 0x00, 0xE0, 0x04, 0x00, 0x0F, 0xE0, 0x00, 0x20, 0x00, 0x00, 0x00, 0x00, 0x00, 0x00, 0x00, 0x00, 0x00, 0x00, 0x00, 0x00}//;
/*const unsigned char PROGMEM frame10 [] =*/	 , {0x00, 0x00, 0x00, 0x00, 0x00, 0x00, 0x00, 0x00, 0x00, 0x00, 0x00, 0x00, 0x00, 0x7E, 0x00, 0x00, 0x3F, 0x00, 0x03, 0xFF, 0x00, 0x00, 0xFF, 0xC0, 0x07, 0xCE, 0x00, 0x00, 0x79, 0xE0, 0x0F, 0x1E, 0x00, 0x00, 0x78, 0xF0, 0x1C, 0x38, 0x1F, 0xF8, 0x1C, 0x38, 0x18, 0x78, 0xFF, 0xFF, 0x1E, 0x18, 0x38, 0xE3, 0xF0, 0x0F, 0xC7, 0x1C, 0x38, 0xCF, 0x80, 0x01, 0xF7, 0x8C, 0x33, 0xDE, 0x00, 0x00, 0x79, 0xCC, 0x37, 0xB8, 0x00, 0x00, 0x1D, 0xEC, 0x37, 0x38, 0x01, 0x80, 0x1E, 0xEC, 0x3E, 0xF0, 0x01, 0x80, 0x0E, 0x7C, 0x3C, 0xE0, 0x01, 0x80, 0x07, 0x3C, 0x39, 0xC0, 0x01, 0x80, 0x03, 0x9C, 0x13, 0x80, 0x01, 0x80, 0x01, 0xC8, 0x03, 0x00, 0x01, 0x80, 0x00, 0xC0, 0x07, 0x00, 0x01, 0x80, 0x00, 0xE0, 0x07, 0x00, 0x01, 0x80, 0x00, 0x60, 0x06, 0x00, 0x01, 0x80, 0x00, 0x60, 0x06, 0x00, 0x01, 0x80, 0x00, 0x70, 0x0E, 0x00, 0x01, 0x80, 0x00, 0x70, 0x0C, 0x00, 0x01, 0x80, 0x00, 0x30, 0x0C, 0x00, 0x01, 0x80, 0x00, 0x30, 0x0C, 0x00, 0xFF, 0x80, 0x00, 0x30, 0x0C, 0x01, 0xFF, 0x80, 0x00, 0x30, 0x0C, 0x00, 0x01, 0x00, 0x00, 0x30, 0x0C, 0x00, 0x00, 0x00, 0x00, 0x30, 0x0C, 0x00, 0x00, 0x00, 0x00, 0x30, 0x0C, 0x00, 0x00, 0x00, 0x00, 0x30, 0x0E, 0x00, 0x00, 0x00, 0x00, 0x70, 0x06, 0x00, 0x00, 0x00, 0x00, 0x60, 0x07, 0x00, 0x00, 0x00, 0x00, 0x60, 0x07, 0x00, 0x00, 0x00, 0x00, 0xC0, 0x03, 0x00, 0x00, 0x00, 0x01, 0xC0, 0x03, 0x80, 0x00, 0x00, 0x01, 0xC0, 0x01, 0xC0, 0x00, 0x00, 0x01, 0x80, 0x00, 0xE0, 0x00, 0x00, 0x07, 0x00, 0x00, 0xE0, 0x00, 0x00, 0x07, 0x00, 0x00, 0x70, 0x00, 0x00, 0x0E, 0x00, 0x00, 0xFC, 0x00, 0x00, 0x3E, 0x00, 0x00, 0xFE, 0x00, 0x00, 0x7F, 0x80, 0x01, 0xC7, 0xC0, 0x03, 0xE3, 0x80, 0x03, 0x83, 0xFC, 0x1F, 0xC1, 0xC0, 0x07, 0x00, 0x7F, 0xFE, 0x00, 0xE0, 0x06, 0x00, 0x0F, 0xF0, 0x00, 0x60, 0x00, 0x00, 0x00, 0x00, 0x00, 0x00}//;
/*const unsigned char PROGMEM frame11 [] =*/	 , {0x00, 0x00, 0x00, 0x00, 0x00, 0x00, 0x00, 0x00, 0x00, 0x00, 0x50, 0x00, 0x00, 0x00, 0x00, 0x03, 0xFE, 0x00, 0x00, 0x00, 0x00, 0x07, 0xFF, 0x00, 0x00, 0x00, 0x00, 0x07, 0xC3, 0x80, 0x03, 0xF8, 0x00, 0x01, 0xC1, 0xC0, 0x0F, 0xF8, 0x00, 0x00, 0xF0, 0xE0, 0x1F, 0x70, 0x1F, 0xF8, 0x78, 0x60, 0x38, 0x60, 0xFF, 0xFF, 0x1C, 0x70, 0x70, 0xE3, 0xF0, 0x0F, 0xCF, 0x30, 0x61, 0xCF, 0x80, 0x01, 0xF7, 0xF0, 0x63, 0x9E, 0x00, 0x00, 0x7B, 0xF0, 0xE3, 0x9C, 0x00, 0x00, 0x38, 0xF0, 0xC7, 0x78, 0x01, 0x80, 0x1E, 0xF0, 0xCF, 0x70, 0x01, 0x80, 0x0E, 0x30, 0xCC, 0xE0, 0x01, 0x80, 0x07, 0x00, 0xFD, 0xC0, 0x01, 0x80, 0x03, 0x80, 0xFB, 0x80, 0x01, 0x80, 0x01, 0xC0, 0xF3, 0x80, 0x01, 0x80, 0x00, 0xC0, 0x67, 0x00, 0x01, 0x80, 0x00, 0xE0, 0x26, 0x00, 0x01, 0x80, 0x00, 0xE0, 0x06, 0x00, 0x01, 0x80, 0x00, 0x60, 0x0E, 0x00, 0x01, 0x80, 0x00, 0x60, 0x0E, 0x00, 0x01, 0x80, 0x00, 0x70, 0x0C, 0x00, 0x01, 0x80, 0x00, 0x30, 0x0C, 0x00, 0x01, 0x80, 0x00, 0x30, 0x0C, 0x00, 0xFF, 0x80, 0x00, 0x30, 0x0C, 0x01, 0xFF, 0x80, 0x00, 0x30, 0x0C, 0x00, 0x00, 0x00, 0x00, 0x30, 0x0C, 0x00, 0x00, 0x00, 0x00, 0x30, 0x0C, 0x00, 0x00, 0x00, 0x00, 0x30, 0x0C, 0x00, 0x00, 0x00, 0x00, 0x30, 0x0E, 0x00, 0x00, 0x00, 0x00, 0x70, 0x06, 0x00, 0x00, 0x00, 0x00, 0x60, 0x07, 0x00, 0x00, 0x00, 0x00, 0xE0, 0x07, 0x00, 0x00, 0x00, 0x00, 0xE0, 0x03, 0x00, 0x00, 0x00, 0x00, 0xC0, 0x03, 0x80, 0x00, 0x00, 0x01, 0xC0, 0x01, 0x80, 0x00, 0x00, 0x03, 0x80, 0x00, 0xE0, 0x00, 0x00, 0x03, 0x00, 0x00, 0xE0, 0x00, 0x00, 0x07, 0x00, 0x00, 0x70, 0x00, 0x00, 0x0E, 0x00, 0x00, 0xFC, 0x00, 0x00, 0x3F, 0x00, 0x00, 0xFE, 0x00, 0x00, 0x7F, 0x00, 0x01, 0xC7, 0xC0, 0x01, 0xE3, 0x80, 0x03, 0x83, 0xF8, 0x2F, 0xC1, 0xC0, 0x07, 0x00, 0x7F, 0xFF, 0x00, 0xE0, 0x06, 0x00, 0x0F, 0xF0, 0x00, 0x60}//;
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
void loop() {  
  for(int i = 0; i < ARRAY_ELEMS ; i++)
  {
    display.clearDisplay();
    display.drawBitmap(xx, yy,frames[i],sizex,sizey, 1);
    display.display();
    delay(tt);
  }
}

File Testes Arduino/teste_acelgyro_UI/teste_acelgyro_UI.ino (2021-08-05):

#include <SPI.h>
#include <Wire.h>
#include <MPU6050.h>
#include <Adafruit_GFX.h> //OLED
#include <Adafruit_SSD1306.h> //OLED
#include <SD.h>
#include "RTClib.h"
#include <math.h>

///
#define SERIAL_BAUDRATE 9600 
#define LED_PIN 13 

///MPU Releated
const short MPU[3] = {0x68, 0x69, 0x68};

int16_t AcX[3] = {16384,0,16384}, 
        AcY[3] = {16384,0,16384}, 
        AcZ[3] = {16384,0,16384}, 
        GyX[3] = {16384,0,16384}, 
        GyY[3] = {16384,0,16384}, 
        GyZ[3] = {16384,0,16384}; //MPU
        
int16_t Acel_convert = 16384;

int16_t Susp[4] = { 4, 5, 6, 7 };   // posição da suspensão
float   Temp[4] = { 8.1, 9.2, 10.3, 11.4 }; // temp dos discos de freio
int16_t Pressao = 12; // pressao do freio     
int16_t VelRoda = 13;
short MultiplexPin[2] = {22, 23}; //posição 1 = pino A
                                //posição 2 = pino B
short sensor_1 = 0, sensor_2 = 1, sensor_3 = 2, sensor_4 = 3;
  
bool Flash = false, Interrupting = false;
#define INTERRUPT_PIN_PRX 19 //pinos que funcionam: 2, 3, 19, 18
#define INTERRUPT_PIN_ANT 18
#define INTERRUPT_PIN_REC 2
///Display related
#define OLED_RESET 4
Adafruit_SSD1306 display(OLED_RESET);

#define SCREEN_WIDTH 128 // OLED display width, in pixels
#define SCREEN_HEIGHT 64 // OLED display height, in pixels

#define LIN_MENU   0
#define COL_MENU1  0
#define COL_MENU2  33
#define COL_MENU3  95

#define LIN_LABEL1    16
#define LIN_LABEL2    32
#define LIN_LABEL3    48
#define COL_LABEL     0

#define LIN_INFO1     16
#define LIN_INFO2     32
#define LIN_INFO3     48
#define COL_INFO      50

#define TEMP_OFFSET   5
#define SUSP_OFFSET   12
#define CONT_OFFSET   8

#define COL1_BOX_ACEL  0
#define COL2_BOX_ACEL  120
#define LIN1_BOX_ACEL  9
#define LIN2_BOX_ACEL  57 //Last value that still appear on screen
#define COL_ACEL_INFO_OFFSET 20
///Opcao selecionada
short opcao = 0;

// ## Serial status ---------------------------------------------------

int didConect = 0; //keeps the value if the connection was made
 /*   WARNING, ERROR AND STATUS CODES                              */
//STATUS
#define MSG_METHOD_SUCCESS 0                      //Code which is used when an operation terminated  successfully
//WARNINGS
#define WRG_NO_SERIAL_DATA_AVAILABLE 250          //Code indicates that no new data is available at the serial input buffer
//ERRORS
#define ERR_SERIAL_IN_COMMAND_NOT_TERMINATED -1   //Code is used when a serial input commands' last char is not a '#' 

// ## Serial status ---------------------------------------------------

//Pino CS do cartao SD
int Pino_CS = 10;
File file;
RTC_DS1307 rtc;
bool grava = false;

///MPU Releated
void getGyroValues(int pMultiplex, int pMPU, int16_t *pGyX, int16_t *pGyY, int16_t *pGyZ) 
{ // MPU 6050 stuff
  if(pMultiplex == 1 || pMultiplex == 2) // se for um dos dois MPUs ligados juntos no primeiro grupo do multiplexador
  {
    digitalWrite(MultiplexPin[0], LOW);
    digitalWrite(MultiplexPin[1], LOW);
  }
  else // se não liga no segundo
  {
    digitalWrite(MultiplexPin[0], HIGH);
    digitalWrite(MultiplexPin[1], LOW);   
  }
  Wire.beginTransmission(pMPU);
  Wire.write(0x43);
  Wire.endTransmission(); //talvez colocar false para não dar problema com o MLX
  Wire.requestFrom(pMPU, 6);
  while(Wire.available() < 6);
  *pGyX = Wire.read()<<8|Wire.read(); //0x43 (GYRO_XOUT_H) & 0x44 (GYRO_XOUT_L)  
  *pGyY = Wire.read()<<8|Wire.read(); //0x45 (GYRO_YOUT_H) & 0x46 (GYRO_YOUT_L)  
  *pGyZ = Wire.read()<<8|Wire.read(); //0x47 (GYRO_ZOUT_H) & 0x48 (GYRO_ZOUT_L)     
}

void getAccelValues(int pMultiplex, int pMPU, int16_t *pAcX, int16_t *pAcY, int16_t *pAcZ) 
{ // MPU 6050 stuff
  if(pMultiplex == 1 || pMultiplex == 2) // se for um dos dois MPUs ligados juntos no primeiro grupo do multiplexador
  {
    digitalWrite(MultiplexPin[0], LOW);
    digitalWrite(MultiplexPin[1], LOW);
  }
  else // se não liga no segundo
  {
    digitalWrite(MultiplexPin[0], HIGH);
    digitalWrite(MultiplexPin[1], LOW);   
  }
  Wire.beginTransmission(pMPU);
  Wire.write(0x3B);
  Wire.endTransmission(); //talvez colocar false para não dar problema com o MLX
  Wire.requestFrom(pMPU, 6);
  while(Wire.available() < 6);
  *pAcX = Wire.read()<<8|Wire.read(); //0x43 (GYRO_XOUT_H) & 0x44 (GYRO_XOUT_L)  
  *pAcY = Wire.read()<<8|Wire.read(); //0x45 (GYRO_YOUT_H) & 0x46 (GYRO_YOUT_L)  
  *pAcZ = Wire.read()<<8|Wire.read(); //0x47 (GYRO_ZOUT_H) & 0x48 (GYRO_ZOUT_L)     
}

void initializeMPU(int pMultiplex, int pMPU)
{
  //Serial.print("Iniciando MPU");
  if(pMultiplex == 1 || pMultiplex == 2) // se for um dos dois MPUs ligados juntos no primeiro grupo do multiplexador
  {
    digitalWrite(MultiplexPin[0], LOW);
    digitalWrite(MultiplexPin[1], LOW);
  }
  else
  {
    digitalWrite(MultiplexPin[0], HIGH);
    digitalWrite(MultiplexPin[1], LOW);   
  }
  //POWER MANAGEMENT RELATED 
  Wire.beginTransmission(pMPU); //escrevendo no endereço do MPU
  Wire.write(0x6B);            //acessando registrador responsável
  Wire.write(0b00000000);      //seta o sleep do MPU-6050 em 0  
  Wire.endTransmission();      //termina a configuração //talvez colocar false para não dar problema com o MLX

  //GYRO CONFIG RELATED
  Wire.beginTransmission(pMPU);
  Wire.write(0x1B);
  Wire.write(0b00000000);
  Wire.endTransmission();//talvez colocar false para não dar problema com o MLX

  //ACCELEROMETER CONFIG RELATED
  Wire.beginTransmission(pMPU);
  Wire.write(0x1C);
  Wire.write(0b00000000);
  Wire.endTransmission();//talvez colocar false para não dar problema com o MLX
}

void readSensorsData(){
  getAccelValues    (sensor_2 + 1,
                     MPU[sensor_2], 
                     &AcX[sensor_2], 
                     &AcY[sensor_2], 
                     &AcZ[sensor_2]);
                     
  getGyroValues     (sensor_2 + 1,
                     MPU[sensor_2], 
                     &GyX[sensor_2], 
                     &GyY[sensor_2], 
                     &GyZ[sensor_2]);
  
}

///

void opcao_mais ()
{
  detachInterrupt(digitalPinToInterrupt(digitalPinToInterrupt(INTERRUPT_PIN_PRX)));
  
   static unsigned long last_interrupt_time = 0;
   unsigned long interrupt_time = millis();
   // If interrupts come faster than 200ms, assume it's a bounce and ignore
   if (interrupt_time - last_interrupt_time > 200)
   {
     opcao++;
     if(opcao > 11)
      opcao = 0;
   }
   last_interrupt_time = interrupt_time;
  
  attachInterrupt(digitalPinToInterrupt(INTERRUPT_PIN_PRX), opcao_mais, FALLING);
}
void opcao_menos ()
{
  detachInterrupt(digitalPinToInterrupt(digitalPinToInterrupt(INTERRUPT_PIN_ANT)));
  
   static unsigned long last_interrupt_time = 0;
   unsigned long interrupt_time = millis();
   // If interrupts come faster than 200ms, assume it's a bounce and ignore
   if (interrupt_time - last_interrupt_time > 200)
   {
     opcao--;
     if(opcao < 0)
      opcao = 11;
   }
   last_interrupt_time = interrupt_time;
  
  attachInterrupt(digitalPinToInterrupt(INTERRUPT_PIN_ANT), opcao_menos, FALLING);
}
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

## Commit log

2019-10-22 Add project files.
    [arduino_mega_bottom - Copy.stl, arduino_mega_bottom.stl, arduino_mega_bottom_extra ajutado.stl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]
2019-10-22 Versão com thread para comunicação serial funcionando e pronto para receber todas as informações dos sensores do arduino. (atualizando comentários)
2019-11-10 Rec and Reset Log buttons configured.
2019-11-13 Possible solution to raspberry pi not comunicating to serial anymore.
2020-05-11 mudado a conexão entre a janela e o Arduino. Agora a janela envia "1#" para o Arduino começar a comunicar e "0#" para parar, sem encerrar a comunicação serial que estava gerando erro e também não é m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
2020-05-24 -Added convertion variables; Now converting values to be displayed(but gyros values are being displayed on accels, and accels on gyros).
2020-08-15 - Retirado referências IronPython. - Adicionado chart, mas será recomvido o padrão e será feita uma classe personalizada para poder funcionar no Raspberry.
2020-10-30 Lots of enchancements. Deleted all chart related files references on project to make it run on raspberry again. Enchandes the data transfer from the string lost to the GUI and added global values of 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
    [arduino_mega_bottom - Copy.stl, arduino_mega_bottom.stl, arduino_mega_bottom_extra ajutado.stl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]
2020-11-30 - feito tela de teste do acelerômetro - feito programa para rodar a tela OLED com botões no arduino - script python em desenvolvimento para funcionar em conjunto com a tela OLED e botões, para que at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
    [MCP2515Calc.xlsx]
2021-01-15 Add files via upload
    Adicionando fotos e vídeos para ilustrar o projeto.
2021-05-13 Janela agr comunicando arduino e lendo a serial.
2021-05-17 Está salvando o log com uma variável de apoio.
2021-05-23 Agora grava ou não de acordo com a info serial.
2021-08-05 Adicionado animações dos testes recentes
    Adicionado animações dos testes que foram feitos com o alerta de bandeira que será enviado dos boxes pro carro e da UI para uma melhor visualização da informação do acelerômetro.
2021-08-09 Atualizado o readme com informações novas.
    Foi adicionado a informação e imagens da base de teste, o aviso de bandeiras e a nova UI para os acelerômetros.
